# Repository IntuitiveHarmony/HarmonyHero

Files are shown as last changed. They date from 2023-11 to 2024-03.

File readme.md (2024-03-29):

# HarmonyHero

### Utilizing an Arduino Pro Micro to convert a Guitar Hero style video game controller into a MIDI controller.

<br>

✨ [Live Demo](https://youtu.be/Pi3ivdWhib0?si=JtICMj6n6GDKvUco)

<br>

🔗 MIDI is a serial protocol that allows electronic or computer based musical instruments to communicate with each other

✅ By completing this conversion the controller be able to control any MIDI enabled synthesizers you happen to have lying around

❌ After the conversion the controller will loose any functionality associated with the video game Guitar Hero

<br>

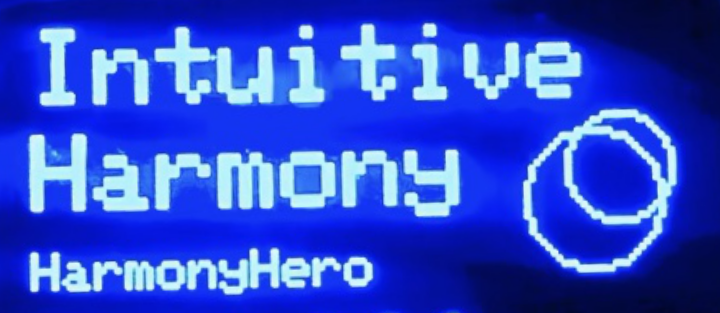
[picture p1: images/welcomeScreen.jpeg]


<br>

## Table of Contents

- [Hardware](#hardware)
  - [Original Components](#original-components)
  - [Added Components](#added-components)
- [Software](#software)
- [Version History](#version-history)
- [Background](#background)
  - [Note Selection 🎶](#note-selection-)
  - [Added Display 🤩](#added-display-)
- [Wiring Diagram](#wiring-diagram)
- [Circuit Overview](#circuit-overview)
  - [🤔 I have a question](#-i-have-a-question)
  - [🤚 Multiplexer has an answer](#-multiplexer-has-an-answer)
- [Maxed Memory](#maxed-memory)
- [A word about MIDI](#a-word-about-midi)
- [Resources / Inspiration](#resources--inspiration)
- [Personal Thanks](#personal-thanks)
- [Contributors](#contributors)
- [License](#license)

## Hardware

### Original Components

_May vary based on brand/version of controller_

| Item | Amount |
| --- | --- |
| Guitar Hero Controller (I used [Mad Catz Fender P-Bass](https://rockband.fandom.com/wiki/Fender_Precision_Bass)) | 1 |
| Fret Board Buttons | 10 |
| Strum Switch Buttons (2x buttons each switch) | 4 |
| Directional Buttons | 4 |
| Menu Buttons | 3 |
| 10k Potentiometers | 2 |
| 3.5mm TRS jack for [Type-A](https://minimidi.world/) MIDI output | 1 |

<br>

### Added Components

| Item | Amount |
| --- | --- |
| Arduino Pro Micro [ATmega32U4](https://cdn.sparkfun.com/datasheets/Dev/Arduino/Boards/ATMega32U4.pdf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) | 1 |
| Single color [OLED SSD Screen](https://www.rajguruelectronics.com/Product/1147/OLED%204%20Pin%200.96%20inch%20128x64%20display%20module%20%20yellow%20bule.pdf) 128x64 (4 pin) | 1 |
| [CD74HC4051](https://www.ti.com/lit/ds/symlink/cd74hc4051.pdf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) Multiplexer (MUX) module | 3 |
| 0.1 uf Capacitors for smoothing out the potentiometers | 2 |
| 220 ohm Resistor for MIDI output | 1 |

<br>

## Software

- [Adafruit_SSD1306 library](https://github.com/adafruit/Adafruit_SSD1306) for display
- [arduino_midi_library](https://github.com/FortySevenEffects/arduino_midi_library/tree/dev) for MIDI functionality
- [EEPROM library](https://docs.arduino.cc/learn/built-in-libraries/eeprom) to persist data across power cycle
- [Custom Code](https://github.com/IntuitiveHarmony/HarmonyHero/blob/master/HarmonyHero.ino) hacked together with 💜 by me

<br>

## Features

- Controls synthesizers and other MIDI instruments
- Added OLED screen to display parameters
- Allows the saving and recalling of five distinct 10-note user-defined tunings
- Permits customization of the MIDI channel and velocity for each tuning
- Four user-defined CC toggles per tuning controlled by the strum switches
- Transposition of tuning up/down an octave or semitone with directional button touch
- Pitch bend up to two semitones by turning potentiometer, knob assembly has spring reset

## Version History

<details>
<summary>
1.0.1
</summary>
Date: 12/15/23

#### Fixes

- Cancel any changes on current tuning when switching to new tuning
- Release held notes when changing tunings
- Whammy feature will reset and respond way better. Is a bit choppy with fast changes

#### Known Issues

- The function `handleHeldNotesWhileTransposing()` will sometimes leave sticky notes if a held note is released while the notes are transposed with the directional keys

<hr>
<br>
</details>
<details>
<summary>
1.0.0
</summary>

Date: 12/7/23

#### Known Issues

- Any held notes will become stuck when switching tunings to another. especially if to another channel
- Whammy bar does not reset when released to neutral position

<hr>
</details>
<br>

## Background

Upon seeing 2 old Guitar Hero controllers at the thrift store I decided to pick one up and turn it into a MIDI controller. The goal was to build program to handle the various button presses available and turn them into meaningful MIDI data. One of the more challenging aspects of this endeavor for me was figuring out a user interface that made sense musically, was easy to interact with and was fun to play while avoiding any heavy modifications to the body of the instrument.

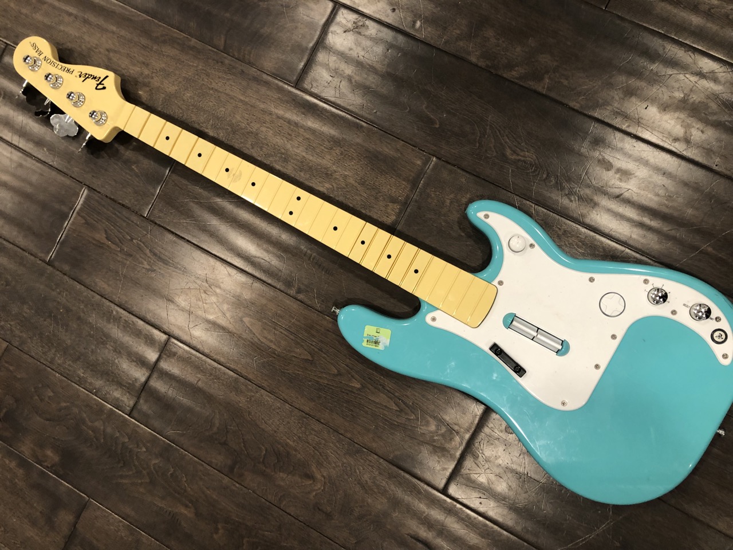
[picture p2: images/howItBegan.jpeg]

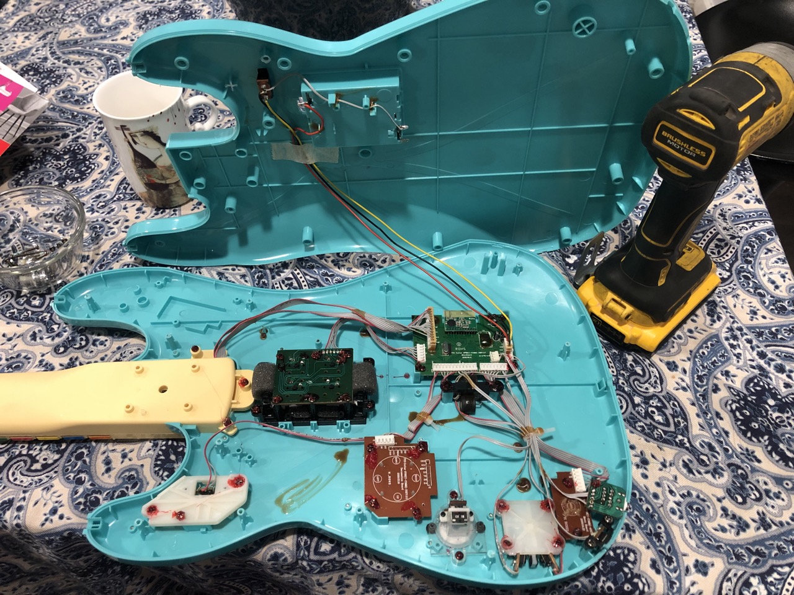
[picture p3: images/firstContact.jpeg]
Guitar Hero Controller Insides


### Note Selection 🎶

Given the 10-button limit on this controller's fret board, I was originally thinking of tuning it to a distinctive 5-note scale, perhaps the minor pentatonic scale. Tuning instruments diatonically (limited to notes within one key) is concept is akin to what you find in certain instruments like tank drums, some glockenspiels, percussion blocks. Sometimes I feel like diatonic tunings can be limiting.

However, I think inspiration can stem from limitations, so my aim was to offer users maximum flexibility while still embracing the constraints of the 10-button fret board. Instead of restricting the user to a predefined scale provided by me, I included the flexibility for the user to change each of the 10 notes on the fret board to one of their choice, thus allowing for custom 10 note scales to be input by the user.

### Added Display 🤩

I also wanted the user to be able to define other parameters such as MIDI channel, note velocity, continuous controller (CC) and have the ability to store and recall different tunings as well. The only way that made sense for me to be able to provide this level of functionality and do so effectively was to introduce a display screen into the mix. Later I will cut a small hole in the body of the guitar in order to make it visible in the final build.

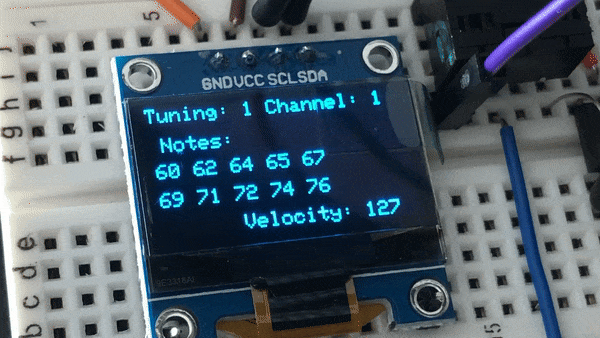
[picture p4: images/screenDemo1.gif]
Early Screen Demo

Early Screen Demo
Early Screen Demo
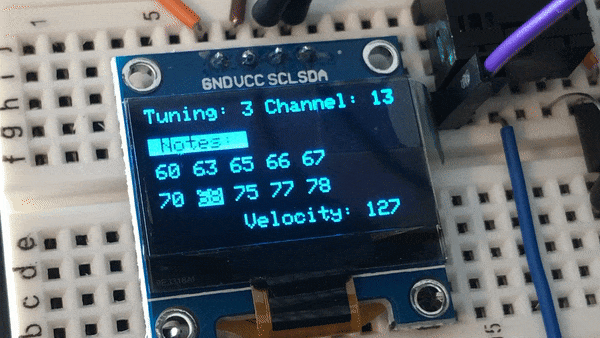
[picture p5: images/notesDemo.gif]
Early Screen Demo


_Early testing of the display_

## Wiring Diagram

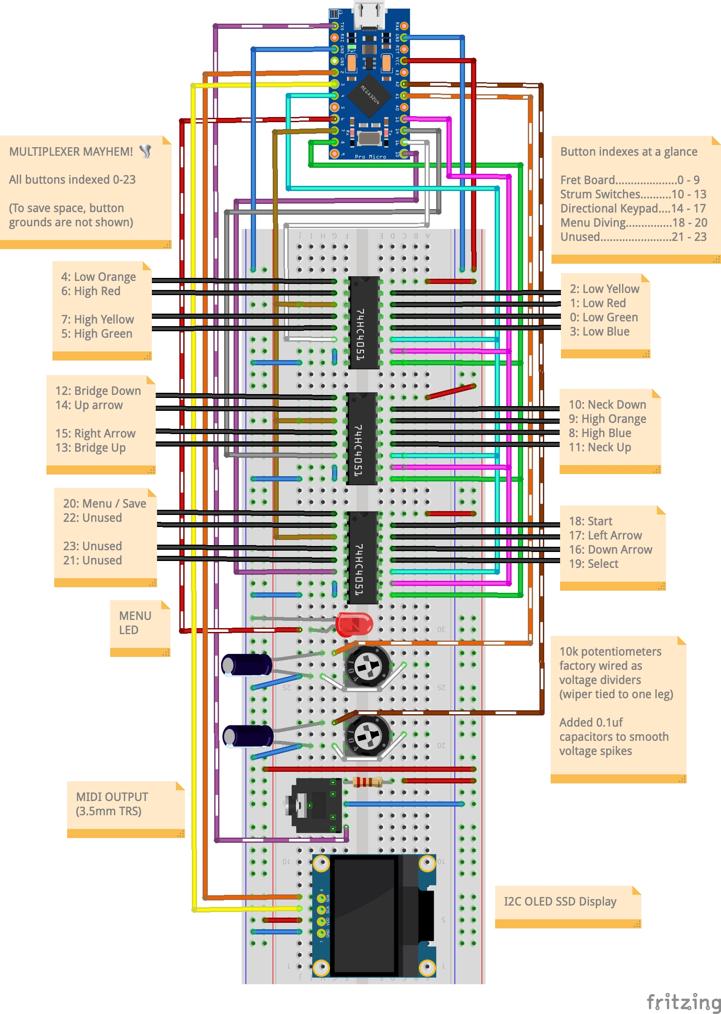
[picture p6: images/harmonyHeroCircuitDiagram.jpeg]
Wiring Diagram


<br>

## Circuit Overview

### 🤔 I have a question

The Pro Micro only has 16 available input pins, so how do we get the information from all of the 22 buttons individually and still have room for the potentiometers and the screen?

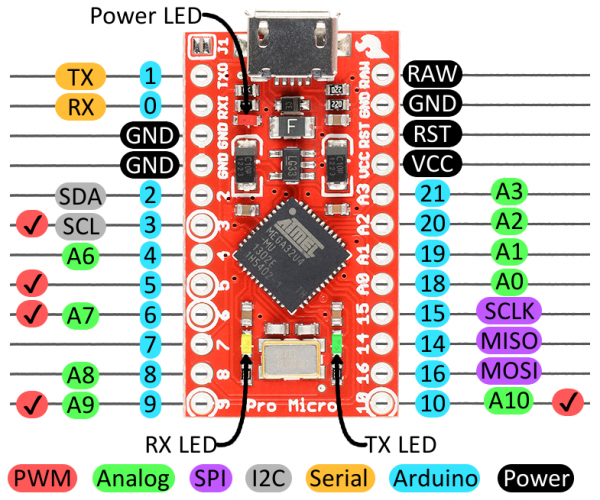
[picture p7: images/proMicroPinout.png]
Pro Micro Pinout


_Pro Micro Pinout_

### 🤚 Multiplexer has an answer

The multiplexer takes input from multiple sources and essentially funnels it into one output, allowing the signal to pass through each channel one at a time. I used CD74HC4051 multiplexers (MUX) in this build, each one allows for 8 inputs. Multiplexers can be stacked as well, so I used 3, giving me the ability, in this case, to connect up to 24 buttons to 1 input pin on the Arduino.

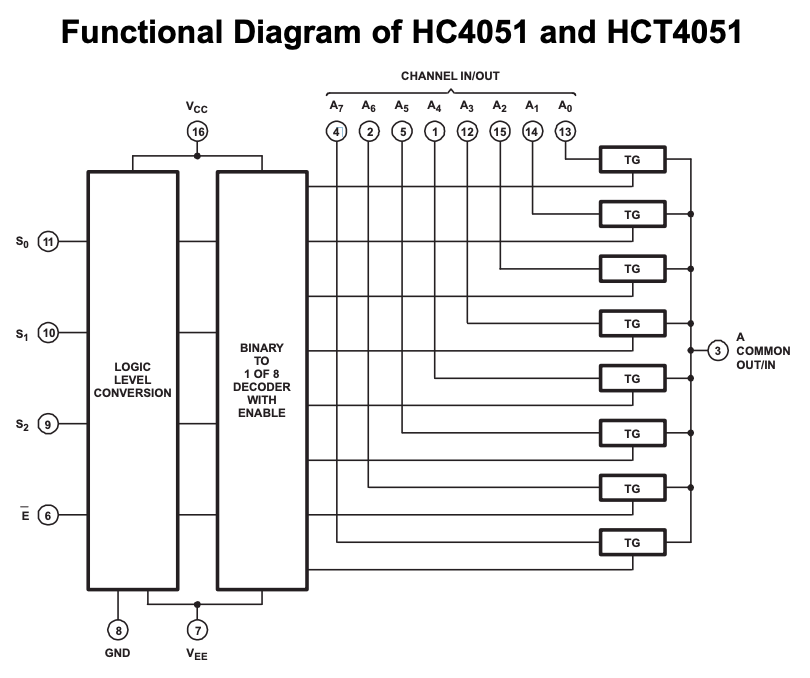
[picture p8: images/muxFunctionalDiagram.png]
Mux Functional Diagram


<br>

There is still a cost when it comes to pins with a multiplexer, the signal pins and the enable pin. Once the dust settles I can connect up to 24 individual buttons to only 7 pins on the Arduino.

- 1 common pin (Where the buttons are funneled to)
- 3 signal pins (To control which button is connected to common)
- 3 enable pins (To turn each individual MUX on or off completely)

The way a multiplexer works is kind of like how a trumpet gets many notes from only three valves, only more simply. In the case of a CD74HC4051 it uses 3 signal pins in various combinations of HIGH and LOW to allow the signal from each of the 8 channels to individually flow through to the common. The next step is enabling and disabling each of the 3 multiplexers via the enable pin, allowing only one to pass the signal at a time. The following truth table from the [data sheet](https://www.ti.com/lit/ds/symlink/cd74hc4051.pdf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) helps by breaking down all the possible combinations of the signal and enable pin of a single MUX. We can then use code to cycle through each channel and MUX individually and very quickly.

<br>

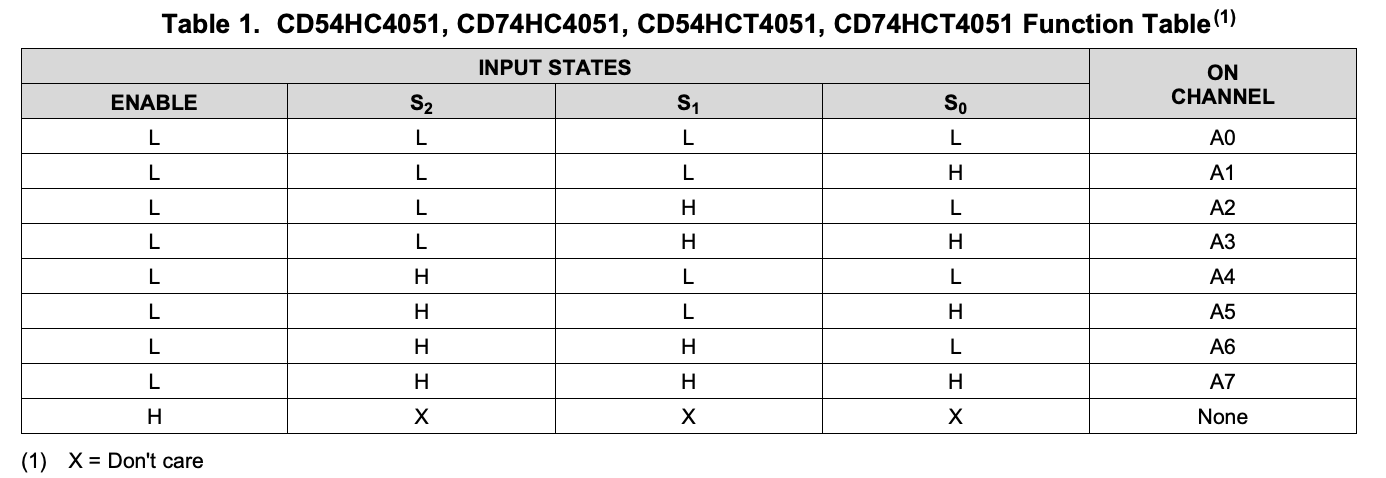
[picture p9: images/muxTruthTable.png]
Mux Truth Table


<br>

This rapid switching through each channel is handled by the following two functions. I relied on chatGPT to help with figuring out the logic for this. This consisted of a 6 hour+ back and forth of prompts and then me tweaking the generated code until I had tuned it to perform the way I intended.

<details>
<summary>Open if you enjoy looking at code</summary>

```c++
void buttonMux() {
  // Loop through all the button channels on the MUX
  for (uint8_t i = 0; i < 24; ++i) {
    // Enable the appropriate MUX
    enableMux(i < 8 ? 0 : (i < 16 ? 1 : 2));

    // Control the selector pins based on the binary representation of i (this all chatGPT 😂)
    // Checks the least significant bit (LSB) of the variable i. The & operator performs a bitwise AND operation
    digitalWrite(signal0, (i & 0x01) ? HIGH : LOW);
    digitalWrite(signal1, (i & 0x02) ? HIGH : LOW);
    digitalWrite(signal2, (i & 0x04) ? HIGH : LOW);

    // Read the value from the selected button
    uint8_t buttonValue = digitalRead(muxCommon);

    // Check for button press
    if (buttonValue == 0 && previousButtonState[i] == 0) {
      // Button is pressed
      previousButtonState[i] = 1;
      handleButtonPress(i);
    }
    // Check for button release
    else if (buttonValue > 0 && previousButtonState[i] == 1) {
      // Button is released
      previousButtonState[i] = 0;
      handleButtonRelease(i);
    }
  }
}

// Use the enable pin on the Multiplexer to turn on only the MUX we want to read
void enableMux(uint8_t mux) {
  switch (mux) {
    case 0:
      digitalWrite(enableMux0, LOW);
      digitalWrite(enableMux1, HIGH);
      digitalWrite(enableMux2, HIGH);
      break;
    case 1:
      digitalWrite(enableMux0, HIGH);
      digitalWrite(enableMux1, LOW);
      digitalWrite(enableMux2, HIGH);
      break;
    case 2:
      digitalWrite(enableMux0, HIGH);
      digitalWrite(enableMux1, HIGH);
      digitalWrite(enableMux2, LOW);
      break;
  }
}
```

</details>

<br>

## Maxed Memory

The program memory for this instrument is around 88%. Running a program that takes up this much space can sometimes cause issues. When I was testing an early version of the controller I was facing an issue where the program would freeze, but only when running on 9v battery power. I was about ready to transfer the code over to an Arduino Mega to try and resolve the issue by using something with more memory. Before I did I rebuilt the test circuit in order to make the transfer to the new board a bit easier.

To my amazement, the program worked perfectly on 9v power while using the original board. I never even tried the Mega. This was a reminder to myself that sometimes starting afresh can resolve challenges.

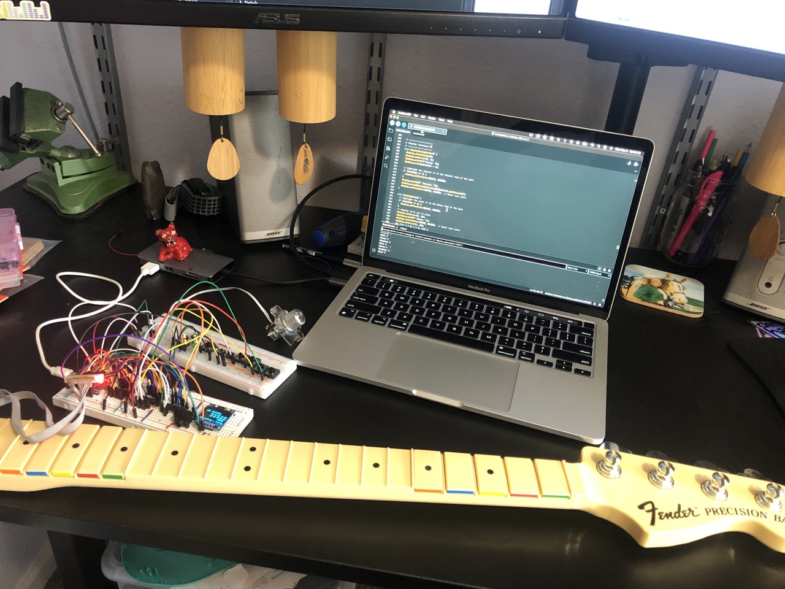
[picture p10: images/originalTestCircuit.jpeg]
Original Test Circuit


_Original test circuit_

<br>

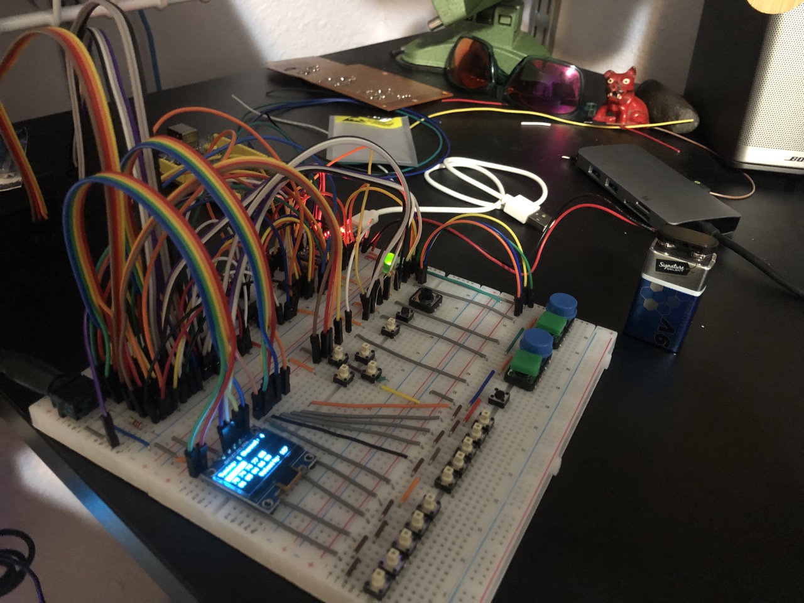
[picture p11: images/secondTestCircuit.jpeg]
Second Test Circuit


_Rebuilt test circuit_

<br>

## A word about MIDI

MIDI stands for Musical Instrument Digital Interface. Ok, great, what does that even mean? The short answer is that MIDI is a way that electronic instruments communicate with each other. So a MIDI controller such as the one I am building doesn't produce or send audio information, it rather sends data. A MIDI controller is just a real-time, data slinger. One of the pieces of data MIDI is used to control is the note data. This comes in the form of a pair of MIDI messages, a `note on` and a `note off` message. They look something like this.

```c++
MIDI.sendNoteOn(note, velocity, channel);
MIDI.sendNoteOff(note, velocity, channel);

```

Each `note on` will be executed the moment a note key is pressed. The `note off` will be executed once the button is released. The note is a value 0-127 and each correlates with a musical note and is what ties the `note off` to the `note on`. (still with me?)

Let's say a function transposes the note while it is being held. Then something like below will more than likely happen causing the original note to play until it a `note off` is played for that note. I call them `sticky notes` and they are pretty annoying. Especially when it is high pitched and I cannot make the right `note off` message happen 😵‍💫.

```c++
MIDI.sendNoteOn(note, velocity, channel);   // Sticky note will play forever...
MIDI.sendNoteOff(newNote, velocity, channel);

```

There are a few instances in the HarmonyHero where there is the potential for this to happen and was indeed happening so many times during testing. To help take care of this I implemented the `handleHeldNotesWhileTransposing` function. It loops through any held notes, triggers their respective `note off`, updates the note by the chosen interval, and then plays the updated note or notes. This make the instrument the sound of "tuning" it while scrolling through the available semitone and octave interval steps.

<details>
<summary>This my favorite function of the project, because of the sound it produces when notes are held and transposed at the same time</summary>

```c++
// Change note on the fly if it being held down, will take care of MIDI note off for any held notes and MIDI on for the updated note value
void handleHeldNotesWhileTransposing(byte semitones) {
  // Check if any notes are being held
  if (numHeldNotes > 0) {
    for (int i = 0; i < numHeldNotes; ++i) {
      uint8_t heldNote = heldNotes[i];
      handleButtonRelease(heldNote);  // Turn off held note
    }
    // This changes the entire array of notes
    if (displayStep == 0 && menuStep == 0) {  // check if on main screen
      for (int i = 0; i < 10; ++i) {          // loop through all notes
        tuningSelection[selection].changeNote(i, semitones);
      }
    }
    // Single Note change
    else if (menuStep == 2) { // Edit single notes menu selection
      tuningSelection[selection].changeNote(selectedNote, semitones);  // update single note in array
    }
    // Play new notes
    for (int i = 0; i < numHeldNotes; ++i) {
      uint8_t heldNote = heldNotes[i];
      handleButtonPress(heldNote);
    }
  }
  // No held notes, simply update
  else if (numHeldNotes == 0) {
    // This targets changing the entire array at once
    if (displayStep == 0 && menuStep == 0) { // Main display screen
      tuningSelection[selection].transposeAllNotes(semitones);
    }
    // Single Note change
    else {
      tuningSelection[selection].changeNote(selectedNote, semitones);
    }
  }
}
```

</details>

<br>

## Resources / Inspiration

- **Notes and Volts**, [MIDI for the Arduino - Circuit Analysis](https://www.youtube.com/watch?v=0L7WAMFWSgY&list=PL4_gPbvyebyH2xfPXePHtx8gK5zPBrVkg&ab_channel=NotesandVolts)
- **minimidi.world**, [A simplified guide to TRS MIDI](https://minimidi.world/)
- **Gustavo Silveira**, [musiconerd.com](https://www.musiconerd.com/)
- **Conrad Menchine**, [Guitar Hero MIDI Controller](https://www.youtube.com/watch?v=obNs_aYCkjY&ab_channel=ConradMenchine)

<br>

## Personal Thanks

- [JP](https://github.com/BoognishSaves) - For all the conversations and testing that made this project more rounded

- [Z](https://github.com/zeusthedrone) - For your expertise during our debugging sessions. The lessons I learned from you have been invaluable to me while navigating the challenges presented by this project. Also, thanks for all your work, helping me with the 3D printed battery cover.

## Contributors

- Jason Horst
- Chat GPT (tedious work, some logic)

## License

This project is licensed under the [MIT License](https://opensource.org/license/mit/).

If you see a way to improve this code, please submit a pull request 😎

<br>

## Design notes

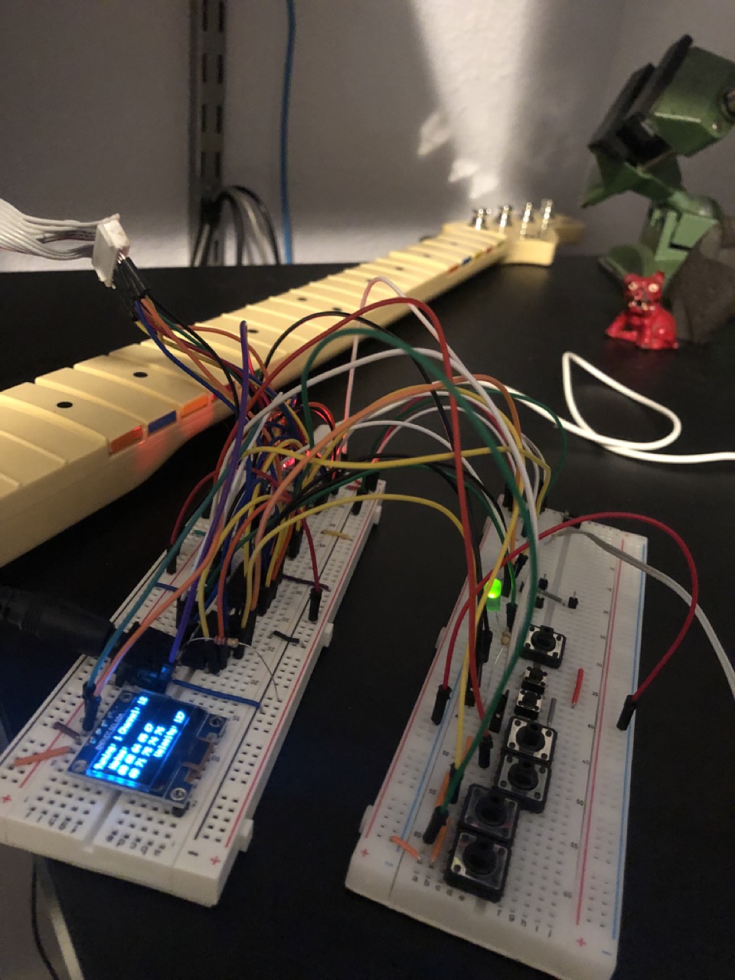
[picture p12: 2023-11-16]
images/moreButtons.jpeg

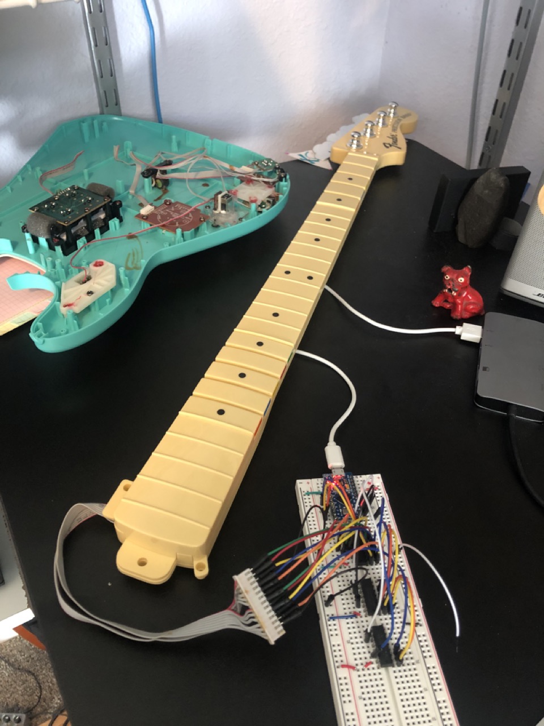
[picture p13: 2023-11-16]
images/mappingButtons.jpeg

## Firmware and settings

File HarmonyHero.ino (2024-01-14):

/*
~~~~~~~~~~~~~~~~~~~~~~~~~~~~~~~~~~~~~~~~~~~~~~~~~~~~~~~~~~~~~~~~~~~~~~~~~~~~~~~~
File:       HarmonyHero.ino
Author:     Jason Horst
Company:    Intuitive Harmony - https://github.com/IntuitiveHarmony
Date:       November 6, 2023
Purpose:    Converting a Guitar Hero controller into a MIDI controller using an
Arduino microcontroller

License:    MIT - https://opensource.org/license/mit/

This software may be freely used, modified, and distributed for any
purpose. The only requirement being the inclusion of this original copyright
notice and disclaimer.
~~~~~~~~~~~~~~~~~~~~~~~~~~~~~~~~~~~~~~~~~~~~~~~~~~~~~~~~~~~~~~~~~~~~~~~~~~~~~~~
*/

// #include <MemoryFree.h>  // Use to check on memory

#include <Adafruit_SSD1306.h>  // For display
#include <Wire.h>              // For display

#include <MIDI.h>  // Add Midi Library

#include <EEPROM.h>  // To save variables across power cycle

// Define OLED parameters
#define SCREEN_WIDTH 128
#define SCREEN_HEIGHT 64
#define OLED_RESET -1  // Reset pin not used with Pro Micro

// OLED display address
#define OLED_I2C_ADDRESS 0x3C

// Create instance of display
Adafruit_SSD1306 display(SCREEN_WIDTH, SCREEN_HEIGHT, &Wire, OLED_RESET);

// Create an instance of the library with default name, serial port and settings
MIDI_CREATE_DEFAULT_INSTANCE();

// Define a flag address in EEPROM
#define INIT_FLAG_ADDRESS 30

// ~~~~~~~~~~~~~~~~~~~~~
// Instrument Parameters
// ~~~~~~~~~~~~~~~~~~~~~
#define MAJOR_VERSION 1
#define MINOR_VERSION 0
#define PATCH_VERSION 1

// ~~~~~~~~~~~~~~
// MUX Parameters
// ~~~~~~~~~~~~~~
// signal pins
#define signal0 4
#define signal1 15
#define signal2 8
// enable pins
#define enableMux0 16
#define enableMux1 14
#define enableMux2 10
// common signal
#define muxCommon 7

// ~~~~~~~~~~~~~~~~~~~~~~
// Main Screen Parameters
// ~~~~~~~~~~~~~~~~~~~~~~
#define MAX_HELD_NOTES 18  // Maximum number of held notes
uint8_t displayStep = 0;   // 0-Notes 1-Neck  2-bridge

uint8_t heldNotes[MAX_HELD_NOTES] = {0};  // Array to store held notes
int numHeldNotes = 0;                     // Number of currently held notes

// ~~~~~~~~~~~~~~~
// Menu Parameters
// ~~~~~~~~~~~~~~~
#define menuLED 6
uint8_t menuStep = 0;  // 0-Home 1-Channel 2-Notes 3-velocity 4-StrumSwitches
uint8_t selectedNote = 0;  // Note to edit, based off index
uint8_t selectedCC = 0;    // CC to edit 0-5 | up 0-2  down 3-5
uint8_t paramUpdated = 0;  // Keep track of when to save
// Keep track of when to display save changes screen
uint8_t saveChangesFlag = 0;

// Keep track of directional buttons being held for speedyParams()
bool paramHeld = false;

// Define constants for LED blinking
#define blinkInterval 450  // Blink interval in milliseconds
// Variable to store the last time LED was updated
unsigned long previousMillisLED = 0;
// Variable to store the start time when a Directional button is held
unsigned long heldParamTime;

// ~~~~~~~~~~~~~~~~~~~
// Selector Parameters
// ~~~~~~~~~~~~~~~~~~~
#define selectPot A1
int selection = 0;
int previousSelection = 0;

// ~~~~~~~~~~~~~~~~~~~
// Whammy Parameters
// ~~~~~~~~~~~~~~~~~~~
#define whammyPot A2
int whammy = 0;
int previousWhammy = 0;

// Array to store the previous state of each button
uint8_t previousButtonState[24] = {0};  // Updated array size

// ~~~~~~~~~~~~~~~~~~~~~~~~~~~~~~~~~~~~~~~~~~~~~
// Tuning class to allow for multiple variations
// ~~~~~~~~~~~~~~~~~~~~~~~~~~~~~~~~~~~~~~~~~~~~~
class Tuning {
 private:
  // Default values can be changed by the user
  byte notes[10] = {};
  byte channel = 1;
  byte velocity = 127;

  // 4 user assignable CC params tied to the strum switches
  // Default Values provided, may not work as anticipated depending on
  // individual synth's local CC routing
  byte neckUpCC = 60;  // MOD wheel
  byte neckUpOff = 60;
  byte neckUpOn = 60;

  byte neckDownCC = 60;  // Portamento
  byte neckDownOffValue = 60;
  byte neckDownOnValue = 60;

  byte bridgeUpCC = 60;  // LFO Depth
  byte bridgeUpOffValue = 60;
  byte bridgeUpOnValue = 60;

  byte bridgeDownCC = 7;  // Volume
  byte bridgeDownOffValue = 127;
  byte bridgeDownOnValue = 0;

 public:
  // constructor
  Tuning(byte initialNotes[10]) {
    // Copy the notes from the provided array to the class's notes array
    memcpy(notes, initialNotes, sizeof(notes));
  }
  // Note Methods
  byte getNote(uint8_t i) { return notes[i]; }
  void changeNote(uint8_t index, byte change) { notes[index] += change; }
  byte getLowestNote() {
    byte minNote = notes[0];
    for (int i = 1; i < sizeof(notes); ++i) {
      if (notes[i] < minNote) {
        minNote = notes[i];
      }
    }
    return minNote;
  }
  byte getHighestNote() {
    byte maxNote = notes[0];
    for (int i = 1; i < sizeof(notes); ++i) {
      if (notes[i] > maxNote) {
        maxNote = notes[i];
      }
    }
    return maxNote;
  }
  void transposeAllNotes(byte semitone) {
    for (int i = 0; i < sizeof(notes); ++i) {
      notes[i] += semitone;
    }
  }

  // Channel Methods
  byte getChannel() { return channel; }
  void changeChannel(byte change) { channel += change; }
  // Velocity methods
  byte getVelocity() { return velocity; }
  void changeVelocity(byte change) { velocity += change; }
  // Control Change Methods ~~~~~~~~~~~~~
  // Neck Up CC Methods
  byte getNeckUpCC() { return neckUpCC; }
  void setNeckUpCC(byte change) { neckUpCC += change; }
  byte getNeckUpOffValue() { return neckUpOff; }
  void setNeckUpOffValue(byte change) { neckUpOff += change; }
  byte getNeckUpOnValue() { return neckUpOn; }
  void setNeckUpOnValue(byte change) { neckUpOn += change; }

  // Neck Down CC Methods
  byte getNeckDownCC() { return neckDownCC; }
  void setNeckDownCC(byte change) { neckDownCC += change; }
  byte getNeckDownOffValue() { return neckDownOffValue; }
  void setNeckDownOffValue(byte change) { neckDownOffValue += change; }
  byte getNeckDownOnValue() { return neckDownOnValue; }
  void setNeckDownOnValue(byte change) { neckDownOnValue += change; }

  // Bridge Up CC Methods
  byte getBridgeUpCC() { return bridgeUpCC; }
  void setBridgeUpCC(byte change) { bridgeUpCC += change; }
  byte getBridgeUpOffValue() { return bridgeUpOffValue; }
  void setBridgeUpOffValue(byte change) { bridgeUpOffValue += change; }
  byte getBridgeUpOnValue() { return bridgeUpOnValue; }
  void setBridgeUpOnValue(byte change) { bridgeUpOnValue += change; }

  // Bridge Down CC Methods
  byte getBridgeDownCC() { return bridgeDownCC; }
  void setBridgeDownCC(byte change) { bridgeDownCC += change; }
  byte getBridgeDownOffValue() { return bridgeDownOffValue; }
  void setBridgeDownOffValue(byte change) { bridgeDownOffValue += change; }
  byte getBridgeDownOnValue() { return bridgeDownOnValue; }
  void setBridgeDownOnValue(byte change) { bridgeDownOnValue += change; }
};
// End of Tuning Class ~~~~~~~~~~~~~~~~~~~~~~~~~

// ~~~~~~~~~~~~~~~
// Initial Tunings
// ~~~~~~~~~~~~~~~
// Major Pentatonic
// MIDI notes: C4, D4, E4, F4, G4, A4, B4, C5, D5, E5
byte notes1[10] = {60, 62, 64, 65, 67, 69, 71, 72, 74, 76};

// C Minor Pentatonic
byte notes2[10] = {60, 63, 65, 67, 69, 72, 74, 75, 77, 79};

// Blues Scale
// MIDI notes: C4, E4, G4, Ab4, A4, C5, D5, F5, G5, Ab5
byte notes3[10] = {60, 63, 65, 66, 67, 70, 72, 75, 77, 78};

// Dorian Scale
// MIDI notes: C4, D4, E4, F4, G4, A4, B4, C5, D5, E5
byte notes4[10] = {60, 62, 63, 65, 67, 69, 71, 72, 74, 76};

// Mixolydian Scale
// MIDI notes: C4, D4, E4, F4, G4, A4, B4, C5, D5, E5
byte notes5[10] = {60, 62, 64, 65, 67, 69, 71, 72, 74, 76};
// byte notes5[10] = { 120, 127, 124, 125, 67, 115, 111, 123, 120, 116 };

// Array of all the tuning instances available
Tuning tuningSelection[5] = {Tuning(notes1), Tuning(notes2), Tuning(notes3),
                             Tuning(notes4), Tuning(notes5)};

// ~~~~~~~~~~~~~
// Arduino Setup
// ~~~~~~~~~~~~~
void setup() {
  Serial.begin(38400);
  // Initialize display
  if (!display.begin(SSD1306_SWITCHCAPVCC, OLED_I2C_ADDRESS)) {
    Serial.println(F("SSD1306 allocation failed"));
    for (;;)
      ;
  }
  // Set display text size and color
  display.setTextSize(1);
  display.setTextColor(SSD1306_WHITE);
  display.clearDisplay();  // Clear the display

  readSelectPot();

  MIDI.begin(MIDI_CHANNEL_OMNI);  // Initialize the Midi Library.

  // Set up the pins
  pinMode(muxCommon, INPUT_PULLUP);

  pinMode(signal0, OUTPUT);  // For MUX
  pinMode(signal1, OUTPUT);  // For MUX
  pinMode(signal2, OUTPUT);  // For MUX

  pinMode(enableMux0, OUTPUT);
  pinMode(enableMux1, OUTPUT);
  pinMode(enableMux2, OUTPUT);

  pinMode(selectPot, INPUT_PULLUP);
  pinMode(whammyPot, INPUT_PULLUP);

  pinMode(menuLED, OUTPUT);

  // Uncomment to initialize the EEPROM Data
  // EEPROM.put(INIT_FLAG_ADDRESS, 0);

  // Check the initialization flag in EEPROM
  byte initFlag;
  EEPROM.get(INIT_FLAG_ADDRESS, initFlag);
  // If the flag is not set, perform the initialization
  if (initFlag != 1) {
    // Save the initial tunings in EEPROM
    for (int i = 0; i < 5; ++i) {
      saveTuningToEEPROM(i);
      delay(10);  // Add a delay between EEPROM writes
    }
    // Set the flag to indicate initialization has been done
    initFlag = 1;
    EEPROM.put(INIT_FLAG_ADDRESS, initFlag);
  }
  // Load tuning data from EEPROM
  for (int i = 0; i < 5; ++i) {
    loadTuningFromEEPROM(i);
  }
  displayStartUp(3000);  // Start screen displays name and version info
}

// ~~~~~~~~~~~~
// Arduino Loop
// ~~~~~~~~~~~~
void loop() {
  // Serial.print("menuStep: ");
  // Serial.print(menuStep);
  // Serial.print(" Selection: ");
  // Serial.print(selection);
  // Serial.print(" prevSel: ");
  // Serial.println(previousSelection);
  // Serial.print("Display: ");
  // Serial.println(displayStep);
  // Serial.print("Menu: ");
  // Serial.println(menuStep);
  // Serial.print("Free Memory: ");  // Use to check on memory
  // Serial.println(freeMemory());   // Use to check on memory

  readSelectPot();
  readWhammyPot();
  buttonMux();
  updateHeldNotes();
  speedyParams();
  lightMenuLED();
  if (whammy != previousWhammy) {
    handleWhammy();
  }
  // Edit menu and display menus have different lengths
  if (menuStep > 0) {
    syncDisplayMenuStep();
  }
  // Normally the Notes and Velocity will display
  if (displayStep == 0) {
    displayTuningHeader();
    displayNotes();
    displayVelocity();
  } else if (displayStep > 0) {
    displayEditStrums();
  }
  if (saveChangesFlag == 1) {
    displaySaveChanges();
  }
  // Update the display at the end of the loop
  display.display();
}

// ~~~~~~~~~~~~
// Button Logic
// ~~~~~~~~~~~~
// Neck buttons..........0-9
// Strum buttons.........10-13 || 10-NeckDown   11-NeckUp     12-BridgeDown
// 13-BridgeUp Directional buttons...14-17 || 14-Up    15-Right    16-Down
// 17-Left Start Button..........18 Select Button.........19 Save / Menu
// Button....20
void handleButtonPress(uint8_t i) {
  // ~~~~~~~~~~~~~~~~~~~~~~~~~~~~~~~~~~~~~~~~~~~~~~~~~~~~~~~~~~~~~~~~~~~~~~~~~~~~~~~~~
  // Send MIDI note on based on the current tuning selection (note, velocity,
  // channel)
  // ~~~~~~~~~~~~~~~~~~~~~~~~~~~~~~~~~~~~~~~~~~~~~~~~~~~~~~~~~~~~~~~~~~~~~~~~~~~~~~~~~
  if (i <= 9) {
    MIDI.sendNoteOn(tuningSelection[selection].getNote(i),
                    tuningSelection[selection].getVelocity(),
                    tuningSelection[selection].getChannel());
  }
  // ~~~~~~~~~~~~~~~~~~~~~~~~~~~~~~~~~~~~~~~~~~~~~~~~~~~~~~~~~~~~~~~~~~~~~~
  // Send MIDI CC messages from the strum buttons (control, value, channel)
  // ~~~~~~~~~~~~~~~~~~~~~~~~~~~~~~~~~~~~~~~~~~~~~~~~~~~~~~~~~~~~~~~~~~~~~~
  else if (i >= 10 && i <= 13) {
    // Neck Down
    if (i == 10) {
      MIDI.sendControlChange(tuningSelection[selection].getNeckDownCC(),
                             tuningSelection[selection].getNeckDownOnValue(),
                             tuningSelection[selection].getChannel());
    }
    // Neck Up
    else if (i == 11) {
      MIDI.sendControlChange(tuningSelection[selection].getNeckUpCC(),
                             tuningSelection[selection].getNeckUpOnValue(),
                             tuningSelection[selection].getChannel());
    }
    // Bridge Down
    else if (i == 12) {
      MIDI.sendControlChange(tuningSelection[selection].getBridgeDownCC(),
                             tuningSelection[selection].getBridgeDownOnValue(),
                             tuningSelection[selection].getChannel());
    }
    // Bridge Up
    else if (i == 13) {
      MIDI.sendControlChange(tuningSelection[selection].getBridgeUpCC(),
                             tuningSelection[selection].getBridgeUpOnValue(),
                             tuningSelection[selection].getChannel());
    }
  }
  // ~~~~~~~~~~~~~~~~~~~
  // Directional buttons
  // ~~~~~~~~~~~~~~~~~~~
  else if (i >= 14 && i <= 17) {
    // Up Button ~~~~~~~~~~~~~~~~~~~~~~~~~~~~~~~~~~~~~~~~~~~~~~~~~~~~~~~~~~~~~~
    // Keep track of when to save
    if (i == 14 && menuStep > 0) {
      paramUpdated = 1;
    }
    // change the MIDI channel up
    if (i == 14 && menuStep == 1) {
      // limit 1-16
      if (tuningSelection[selection].getChannel() < 16) {
        tuningSelection[selection].changeChannel(1);
      }
    }
    // Change the velocity up
    else if (i == 14 && menuStep == 3) {
      // limit 0-127
      if (tuningSelection[selection].getVelocity() < 127) {
        tuningSelection[selection].changeVelocity(1);
      }
    }
    // Change the selected note up
    else if (i == 14 && menuStep == 2) {
      // limit 0-127
      if (tuningSelection[selection].getNote(selectedNote) < 127) {
        // Change note on the fly if it being held down, will take care of MIDI
        // note off errors
        handleHeldNotesWhileTransposing(1);
      }
    }
    // ~~~~~~~~~~~~~~~~~~~~~~
    // Up Arrow CC Monster 👹
    // ~~~~~~~~~~~~~~~~~~~~~~
    // Change Neck Down CC
    else if (i == 14 && menuStep == 4) {
      if (selectedCC == 0) {
        // limit 0-127
        if (tuningSelection[selection].getNeckDownCC() < 127) {
          tuningSelection[selection].setNeckDownCC(1);
        }
      }
      // Change Neck Down Off Value
      else if (selectedCC == 1) {
        // limit 0-127
        if (tuningSelection[selection].getNeckDownOffValue() < 127) {
          tuningSelection[selection].setNeckDownOffValue(1);
          // Send the off CC as it is Updated
          MIDI.sendControlChange(
              tuningSelection[selection].getNeckDownCC(),
              tuningSelection[selection].getNeckDownOffValue(),
              tuningSelection[selection].getChannel());
        }
      }
      // Change Neck Down On Value
      else if (selectedCC == 2) {
        // limit 0-127
        if (tuningSelection[selection].getNeckDownOnValue() < 127) {
          tuningSelection[selection].setNeckDownOnValue(1);
        }
      }
      // Change Neck Up CC Value
      else if (selectedCC == 3) {
        // limit 0-127
        if (tuningSelection[selection].getNeckUpCC() < 127) {
          tuningSelection[selection].setNeckUpCC(1);
        }
      }
      // Change Neck Up Off Value
      else if (selectedCC == 4) {
        // limit 0-127
        if (tuningSelection[selection].getNeckUpOffValue() < 127) {
          tuningSelection[selection].setNeckUpOffValue(1);
          // Send the off CC as it is updated
          MIDI.sendControlChange(tuningSelection[selection].getNeckUpCC(),
                                 tuningSelection[selection].getNeckUpOffValue(),
                                 tuningSelection[selection].getChannel());
        }
      }
      // Change Neck Up On Value
      else if (selectedCC == 5) {
        // limit 0-127
        if (tuningSelection[selection].getNeckUpOnValue() < 127) {
          tuningSelection[selection].setNeckUpOnValue(1);
        }
      }
    }

    // Change Bridge Down CC
    else if (i == 14 && menuStep == 5) {
      if (selectedCC == 0) {
        // limit 0-127
        if (tuningSelection[selection].getBridgeDownCC() < 127) {
          tuningSelection[selection].setBridgeDownCC(1);
        }
      }
      // Change Bridge Down CC
      else if (selectedCC == 1) {
        // limit 0-127
        if (tuningSelection[selection].getBridgeDownOffValue() < 127) {
          tuningSelection[selection].setBridgeDownOffValue(1);
          // Send the off CC as it is Updated
          MIDI.sendControlChange(
              tuningSelection[selection].getBridgeDownCC(),
              tuningSelection[selection].getBridgeDownOffValue(),
              tuningSelection[selection].getChannel());
        }
      }
      // Change Bridge Down On Value
      else if (selectedCC == 2) {
        // limit 0-127
        if (tuningSelection[selection].getBridgeDownOnValue() < 127) {
          tuningSelection[selection].setBridgeDownOnValue(1);
        }
      }
      // Change Bridge Up CC Value
      else if (selectedCC == 3) {
        // limit 0-127
        if (tuningSelection[selection].getBridgeUpCC() < 127) {
          tuningSelection[selection].setBridgeUpCC(1);
        }
      }
      // Change Bridge Up Off Value
      else if (selectedCC == 4) {
        // limit 0-127
        if (tuningSelection[selection].getBridgeUpOffValue() < 127) {
          tuningSelection[selection].setBridgeUpOffValue(1);
          // Send the off CC as it is updated
          MIDI.sendControlChange(
              tuningSelection[selection].getBridgeUpCC(),
              tuningSelection[selection].getBridgeUpOffValue(),
              tuningSelection[selection].getChannel());
        }
      }
      // Change Bridge Up On Value
      else if (selectedCC == 5) {
        // limit 0-127
        if (tuningSelection[selection].getBridgeUpOnValue() < 127) {
          tuningSelection[selection].setBridgeUpOnValue(1);
        }
      }
    }
    // ~~~~~~ End of the UP Arrow CC 👹 ~~~~~~~~~~~~~~~~
    // Transpose all notes one semitone up
    if (i == 14 && menuStep == 0) {
      // check to make sure notes don't go above 127
      if (tuningSelection[selection].getHighestNote() <= 126) {
        handleHeldNotesWhileTransposing(1);
        // paramUpdated = 1;
      }
    }
    // Up Button End ~~~~~~~~~~~~~~~~~~~~~~~~~~~~~~~~~~~~~~~~~~~~~~~~~~~~~~~~~~
    // Right Button ~~~~~~~~~~~~~~~~~~~~~~~~~~~~~~~~~~~~~~~~~~~~~~~~~~~~~~~~~~~
    // Scroll right through notes
    else if (i == 15 && menuStep == 2) {
      // Limit to 0-9
      if (selectedNote < 9) {
        selectedNote++;
      } else {
        selectedNote = 0;
      }
    }
    // Scroll right through CC values
    // for both neck and bridge
    else if (i == 15 && menuStep >= 4) {
      // Limit to 0-5
      if (selectedCC < 5) {
        selectedCC++;
      } else {
        selectedCC = 0;
      }
    }
    // Transpose all notes one Octave up
    if (i == 15 && menuStep == 0) {
      // check to make sure notes don't go above 127
      if (tuningSelection[selection].getHighestNote() <= 115) {
        handleHeldNotesWhileTransposing(12);
      }
    }
    // Right Button End ~~~~~~~~~~~~~~~~~~~~~~~~~~~~~~~~~~~~~~~~~~~~~~~~~~~~~~~
    // Down Button ~~~~~~~~~~~~~~~~~~~~~~~~~~~~~~~~~~~~~~~~~~~~~~~~~~~~~~~~~~~~
    // change the MIDI channel down
    if (i == 16 && menuStep == 1) {
      // limit 1-16
      if (tuningSelection[selection].getChannel() > 1) {
        tuningSelection[selection].changeChannel(-1);
      }
    }
    // Change the selected note down
    else if (i == 16 && menuStep == 2) {
      // limit 0-127
      if (tuningSelection[selection].getNote(selectedNote) > 0) {
        // Change note on the fly if it being held down, will take care of MIDI
        // note off errors
        handleHeldNotesWhileTransposing(-1);
      }
    }
    // Change the velocity down
    else if (i == 16 && menuStep == 3) {
      // limit 0-127
      if (tuningSelection[selection].getVelocity() > 0) {
        tuningSelection[selection].changeVelocity(-1);
      }
    }
    // ~~~~~~~~~~~~~~~~~~~~~~~~
    // Down Arrow CC Monster 👹
    // ~~~~~~~~~~~~~~~~~~~~~~~~
    // Change Neck Down CC
    else if (i == 16 && menuStep == 4) {
      if (selectedCC == 0) {
        // limit 0-127
        if (tuningSelection[selection].getNeckDownCC() > 0) {
          tuningSelection[selection].setNeckDownCC(-1);
        }
      }
      // Change Neck Down Off
      else if (selectedCC == 1) {
        // limit 0-127
        if (tuningSelection[selection].getNeckDownOffValue() > 0) {
          tuningSelection[selection].setNeckDownOffValue(-1);
          // Send the off CC as it is Updated
          MIDI.sendControlChange(
              tuningSelection[selection].getNeckDownCC(),
              tuningSelection[selection].getNeckDownOffValue(),
              tuningSelection[selection].getChannel());
        }
      }
      // Change Neck Down On Value
      else if (selectedCC == 2) {
        // limit 0-127
        if (tuningSelection[selection].getNeckDownOnValue() > 0) {
          tuningSelection[selection].setNeckDownOnValue(-1);
        }
      }
      // Change Neck Up CC Value
      else if (selectedCC == 3) {
        // limit 0-127
        if (tuningSelection[selection].getNeckUpCC() > 0) {
          tuningSelection[selection].setNeckUpCC(-1);
        }
      }
      // Change Neck Up Off Value
      else if (selectedCC == 4) {
        // limit 0-127
        if (tuningSelection[selection].getNeckUpOffValue() > 0) {
          tuningSelection[selection].setNeckUpOffValue(-1);
          // Send the off CC as it is updated
          MIDI.sendControlChange(tuningSelection[selection].getNeckUpCC(),
                                 tuningSelection[selection].getNeckUpOffValue(),
                                 tuningSelection[selection].getChannel());
        }
      }
      // Change Neck Up On Value
      else if (selectedCC == 5) {
        // limit 0-127
        if (tuningSelection[selection].getNeckUpOnValue() > 0) {
          tuningSelection[selection].setNeckUpOnValue(-1);
        }
      }
    }
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

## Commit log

2023-10-27 close to isolating buttons, getting pairs
2023-10-27 buttons isolated
2023-10-27 button release
2023-11-02 move button pin to 7, selector pin to 15
2023-11-04 limit velocity to 0-127
2023-11-04 get left and right buttons ready
2023-11-05 new menu arrangement, strum switch methods
2023-11-05 default strum switches
2023-11-06 save changes across power cycle
2023-11-06 save changes across power cycle, 1st tuning fixed
2023-11-07 splash screen circles, main menu display 🐛 hunt
2023-11-10 comments, remove load splash screen
    [Guitar Hack Diagram.fzz]
2023-11-12 whammy pot and responsiveness, comments, bug search
    [guitarHeroHack.ino]
2023-11-16 rebuilt physical circuit, no more freeze issues 🤔
    [guitarHeroHack.ino]
2023-11-16 whammy pot in business ✌️
2023-11-16 define constants, whammyPoy handling, readme
    [Guitar Hack Diagram.fzz]
2023-11-17 Wiring Diagram
    [Guitar Hack Diagram.fzz]
2023-11-17 Wiring Diagram update
    [Guitar Hack Diagram.fzz]
2023-11-18 Wiring Diagram, readme
    [Guitar Hack Diagram.fzz]
2023-12-15 cancel changes when switching tunings
